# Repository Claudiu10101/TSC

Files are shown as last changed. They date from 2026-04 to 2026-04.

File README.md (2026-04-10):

## 1. Descrierea Detaliată a Funcționalității Hardware

Sistemul este un ceas inteligent (smartwatch) cu consum ultra-redus de energie, bazat pe SoC-ul **nRF52840**, care integrează conectivitate Bluetooth Low Energy (BLE) și un afișaj de tip E-Paper (E-Ink).

### Module și Componente Cheie:
* **Unitatea Centrală (MCU):** **nRF52840** (Cortex-M4F la 64MHz). Este ales pentru suportul hardware de Floating Point (necesar procesării datelor de la senzori) și pentru managementul avansat al energiei.
* **Afișajul (E-Paper):** Spre deosebire de ecranele LCD/OLED, acesta consumă energie **doar la schimbarea imaginii**. Circuitul de control (E-Paper Drive) utilizează un convertor boost format din inductorul **L5 (68µH)** și diodele **MBR0530** pentru a genera tensiunile de ±15V necesare orientării particulelor de pigment din ecran.
* **Managementul Bateriei (Power Management):**
    * **Charger (BQ25180):** Permite încărcarea controlată prin USB și monitorizarea prin I2C.
    * **Fuel Gauge (MAX17048):** Folosește algoritmul *ModelGauge* pentru a estima procentul bateriei fără a necesita un rezistor de descărcare (shunt), economisind energie.
    * **Regulator Buck-Boost (RT6160):** Menține constantă tensiunea de 3.3V chiar și când bateria scade sub acest prag (până la 2.5V), maximizând timpul de utilizare.
* **Senzori și Feedback:**
    * **Accelerometru (BMA423):** Include funcții hardware pentru numărarea pașilor (pedometer) și detectarea gestului de "ridicare mână" (tilt-to-wake), trimițând o întrerupere către MCU pentru a-l trezi din sleep.
    * **Haptic Driver (DRV2605):** Permite generarea de efecte de vibrație complexe (peste 100 de librării incluse) pentru notificări discrete.

### Specificații de Comunicație:
* **I2C (Inter-Integrated Circuit):** Lucrează la 400kHz (Fast Mode). Conectează Charger-ul, Fuel Gauge-ul, IMU-ul și Haptic Driver-ul. Această magistrală este ideală pentru senzori datorită simplității și consumului redus.
* **SPI (Serial Peripheral Interface):** Folosit exclusiv pentru ecranul E-Paper pentru a asigura o rată de transfer a datelor suficient de mare pentru refresh-ul imaginii.

---

## 2. Diagrama bloc

```mermaid
graph TD
    %% -- Nodul Central (Microcontroller) --
    subgraph MCU_Block ["Nucleu Central"]
        nRF52840["nRF52840 SoC (Bluetooth 5 / RF)"]
    end

    %% -- Modulul Power Management --
    subgraph Power_Block ["Management Alimentare"]
        LiPo_Batt(("Baterie LiPo 3.7V"))
        USBC_Conn["Conector USB-C (Alimentare/Date)"]
        Charger_BQ["BQ25180 Charger IC"]
        Fuel_MAX["MAX17048 Fuel Gauge"]
        Reg_RT["RT6160 Buck-Boost Regulator"]
    end

    %% -- Modulul Afișaj --
    subgraph Display_Block ["Interfață Vizuală"]
        FPC_Conn["Conector FPC 24p"]
        EPD_Driver["Circuit Comandă E-Paper"]
        EPD_Screen["Ecran E-Paper (E-Ink)"]
    end

    %% -- Modulul Senzori & Feedback --
    subgraph Sensor_Feedback_Block ["Senzori și Actuatori"]
        IMU_BMA["BMA423 Accelerometru"]
        Haptic_DRV["DRV2605 Haptic Driver"]
        Haptic_Mot(("Motor Vibrații"))
    end

    %% -- Linii de Alimentare --
    USBC_Conn ==> Charger_BQ
    LiPo_Batt <==> Charger_BQ
    LiPo_Batt -.-> Fuel_MAX
    Charger_BQ ==> Reg_RT
    Reg_RT ==> nRF52840
    Reg_RT ==> IMU_BMA
    Reg_RT ==> FPC_Conn
    Reg_RT ==> Haptic_DRV

    %% -- Linii de Date --
    nRF52840 <-->|I2C| Charger_BQ
    nRF52840 <-->|I2C| Fuel_MAX
    nRF52840 <-->|I2C| IMU_BMA
    nRF52840 <-->|I2C| Haptic_DRV
    nRF52840 -->|SPI| FPC_Conn
    FPC_Conn <--> EPD_Driver
    EPD_Driver ==> EPD_Screen
```

## 3. Configurarea Pinilor nRF52840 (Pinout Mapping)

Alegerea pinilor pe nRF52840 este critică pentru a evita interferențele și pentru a optimiza rutarea semnalelor RF.

| Pin MCU | Funcție Schematic | Explicație și Justificare |
| :--- | :--- | :--- |
| **P0.26 / P0.27** | **SDA / SCL** | **Magistrala I2C.** Sunt pini digitali generali. S-au ales acești pini pentru a păstra magistrala de senzori grupată fizic pe PCB. |
| **P1.01** | **EPD_BUSY** | **Intrare digitală.** MCU citește acest pin pentru a ști când ecranul a terminat operațiunea de refresh (activ high). |
| **P1.02** | **EPD_RES** | **Reset ecran.** Pin digital folosit pentru inițializarea hardware a controlerului de display. |
| **P1.03** | **EPD_DC** | **Data/Command.** Semnal de control SPI care indică dacă datele trimise sunt comenzi sau pixeli. |
| **P1.04** | **EPD_CS** | **Chip Select.** Activează comunicația SPI cu ecranul. |
| **P1.05** | **EPD_SCK** | **SPI Clock.** Generat de MCU pentru sincronizarea datelor către ecran. |
| **P1.06** | **EPD_MOSI** | **Master Out Slave In.** Linia principală de date către afișaj. |
| **P0.11** | **INT_IMU** | **Intrare Întrerupere.** Conectat la pinul INT1 al BMA423. Trezește procesorul din modul System OFF la detectarea mișcării. |
| **P0.03** | **HAPTIC_EN** | **Trigger.** Activează driverul de vibrații. Poate fi folosit și cu PWM pentru intensitate variabilă. |
| **P0.02, P0.29, P0.31** | **Buttons (UP, ENT, DN)** | **Interfață Utilizator.** Configurați cu Pull-Up intern. Sunt pini capabili de "Sense" pentru a trezi dispozitivul din moduri de consum ultra-redus. |

### Calcule și Considerente de Consum:
1.  **Mod Sleep (Deep Sleep):** Cu nRF52840 în modul *System ON Idle* și senzorii în mod *Low Power*, consumul estimat este de aproximativ **15-20 µA**.
2.  **Refresh Ecran:** În timpul celor 1-2 secunde de refresh E-Paper, consumul sare la **5-10 mA** datorită convertorului boost.
3.  **Baterie:** Folosind o baterie LiPo de 100mAh, cu un management corect al sleep-ului, autonomia poate depăși **2-3 săptămâni**.

Acest design respectă rigurozitatea cerută în cadrul cursului TSC, punând accent pe utilizarea eficientă a perifericelor hardware ale nRF52840 și pe independența modulelor față de CPU prin utilizarea întreruperilor.

### 4. Bill of materials

| Cantitate | Componentă / Modul | Designator (Parts) | Descriere Scurtă | Link Achiziție / Resurse | Datasheet / Link Producător |
| :--- | :--- | :--- | :--- | :--- | :--- |
| 1 | **nRF52840** | U$1 | [cite_start]Microcontroler Bluetooth [cite: 738, 740] | [Mouser/Search](https://www.mouser.com) | [Nordic Semi](https://www.google.com/search?q=https://www.nordicsemi.com) |
| 1 | **2450AT18B100E** | ANT1 | [cite_start]Antenă Chip 2.45GHz [cite: 358, 360] | [cite_start][Arrow Link](https://www.arrow.com/en/products/2450at18b100e/johanson-dielectrics) [cite: 360] | [cite_start][Johanson Tech](https://www.google.com/search?q=https://www.mouser.co.uk/ProductDetail/Johanson-Technology/2450at18b100e) [cite: 364] |
| 1 | **BQ25180YBGR** | IC1 | [cite_start]Charger IC Li-Ion/Polymer [cite: 574, 576] | [cite_start][Mouser Link](https://www.google.com/search?q=https://www.mouser.co.uk/ProductDetail/Texas-Instruments/BQ25180YBGR) [cite: 581] | [cite_start][Texas Instruments](https://www.google.com/search?q=https://www.arrow.com/en/products/bq25180ybgr/texas-instruments) [cite: 576] |
| 1 | **RT6160AWSC** | IC2 | [cite_start]Buck-Boost Regulator [cite: 755, 757] | [cite_start][Mouser Link](https://www.google.com/search?q=https://www.mouser.co.uk/ProductDetail/Richtek/RT6160AWSC) [cite: 762] | [cite_start][Richtek](https://www.google.com/search?q=https://www.mouser.co.uk/ProductDetail/Richtek/RT6160AWSC) [cite: 762] |
| 1 | **BMA423** | IC3 | [cite_start]Accelerometru 3 axe [cite: 559, 561] | [cite_start][Mouser Link](https://www.google.com/search?q=https://www.mouser.co.uk/ProductDetail/Bosch-Sensortec/BMA423) [cite: 566] | [cite_start][Bosch Sensortec](https://www.arrow.com/en/products/bma423/bosch) [cite: 562] |
| 1 | **DRV2605YZFR** | IC4 | [cite_start]Haptic Driver (ERM/LRA) [cite: 604, 606] | [cite_start][Arrow Link](https://www.arrow.com/en/products/drv2605yzfr/texas-instruments) [cite: 606] | [cite_start][Texas Instruments](https://www.arrow.com/en/products/drv2605yzfr/texas-instruments) [cite: 606] |
| 1 | **FTC252012SR47MBCA** | L1 | [cite_start]Inductor 0.47µH [cite: 706, 707] | [cite_start][**JLC Parts (C5832368)**](https://jlcpcb.com/partdetail/6763488-FTC252012SR47MBCA/C5832368) [cite: 712] | [cite_start][TDK](https://jlcpcb.com/partdetail/6763488-FTC252012SR47MBCA/C5832368) [cite: 712] |
| 1 | **KH-TYPE-C-16P** | J2 | [cite_start]Conector USB-C 16 pini [cite: 691, 692] | [cite_start][SnapEDA Link](https://www.snapeda.com/parts/KH-TYPE-C-16P/Kinghelm/view-part/?ref=snap) [cite: 703] | [cite_start][Kinghelm](https://www.snapeda.com/parts/KH-TYPE-C-16P/Kinghelm/view-part/?ref=eda) [cite: 694] |
| 1 | **503480-2400** | J1 | [cite_start]Conector FPC 24 pini [cite: 493, 494] | [cite_start][Mouser Link](https://www.google.com/search?q=https://www.mouser.co.uk/ProductDetail/Molex/503480-2400) [cite: 500] | [cite_start][Molex](https://www.google.com/search?q=https://www.mouser.co.uk/ProductDetail/Molex/503480-2400) [cite: 500] |
| 3 | **MBR0530** | D1, D2, D3 | [cite_start]Diodă Schottky 0.5A 30V [cite: 632, 634] | [cite_start][SnapEDA Link](https://www.snapeda.com/parts/MBR0530/Onsemi/view-part/?ref=snap) [cite: 642] | [cite_start][ON Semi](https://www.snapeda.com/parts/MBR0530/Onsemi/view-part/?ref=eda) [cite: 636] |
| 1 | **USBLC6-2SC6Y** | D4 | [cite_start]Protecție ESD SOT-23-6 [cite: 619, 621] | [cite_start][SnapEDA Link](https://www.snapeda.com/parts/USBLC6-2SC6Y/STMicroelectronics/view-part/?ref=snap) [cite: 629] | [cite_start][STMicro](https://www.snapeda.com/parts/USBLC6-2SC6Y/STMicroelectronics/view-part/?ref=eda) [cite: 622] |
| 1 | **SI1308EDL-T1-GE3** | Q1 | [cite_start]MOSFET N-Ch 30V 1.5A [cite: 646, 647] | [cite_start][SnapEDA Link](https://www.snapeda.com/parts/SI1308EDL-T1-GE3/Vishay+Siliconix/view-part/?ref=snap) [cite: 656] | [cite_start][Vishay](https://www.snapeda.com/parts/SI1308EDL-T1-GE3/Vishay+Siliconix/view-part/?ref=eda) [cite: 648] |
| 3 | **EVP-AKE31A** | SW1-SW3 | [cite_start]Întrerupător (Switch) [cite: 326, 327] | [Panasonic Search](https://www.mouser.com) | [Panasonic](https://www.mouser.com) |
| 1 | **TC2030-IDC** | J3 | [cite_start]Adaptor programare 6 pini [cite: 770, 771] | [Tag-Connect](https://www.tag-connect.com) | [cite_start][Tag-Connect](https://www.tag-connect.com) [cite: 776] |

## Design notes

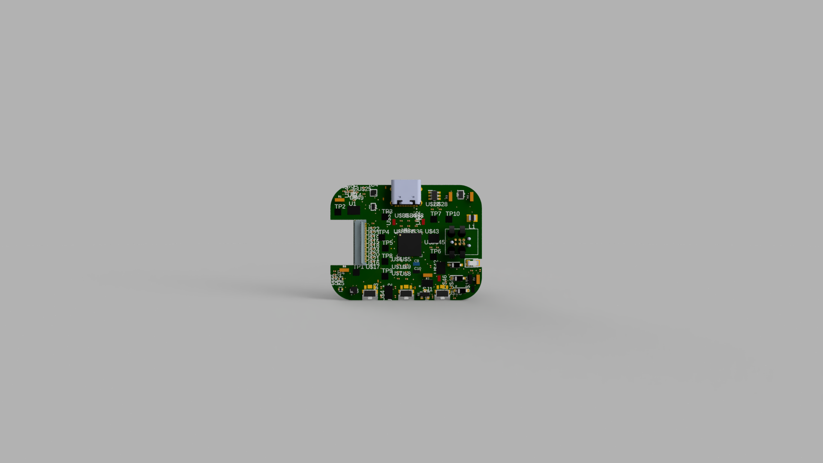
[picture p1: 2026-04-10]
Images/170cff6c-68ed-45f0-8952-ea8ea06512d7.PNG

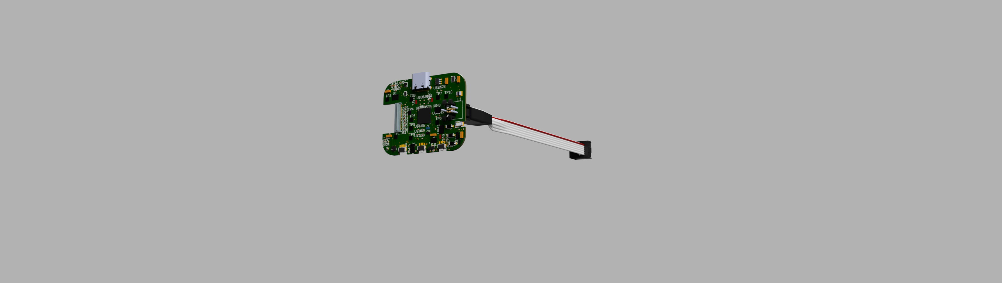
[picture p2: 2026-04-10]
Images/InkTime.fbrd_2026-Apr-10_02-35-59PM-000_CustomizedView54129638116.png

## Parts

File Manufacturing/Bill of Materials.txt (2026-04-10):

Partlist exported from Fusion Hub: Alexe   Project: iiytkhgjh  Board: InkTime.fbrd at 4/10/2026 7:06 AM

Qty Value                                            Device                                                                       Package                                                                                                                Parts                                                Description                                                                                                               ARROW_PART_NUMBER ARROW_PRICE-STOCK                                                                                AVAILABILITY CATEGORY  CHECK_PRICES                                                                       DATASHEET DESCRIPTION                                                                                              HEIGHT                                    JLCPCB       MANUFACTURER                                        MANUFACTURER_NAME                                                MANUFACTURER_PART_NUMBER MF                 MOUSER_PART_NUMBER MOUSER_PRICE-STOCK                                                                                           MP                                                                                                       MPN OPERATING_TEMPERATURE PACKAGE                     PACKAGE_SIZE PACKAGE_TYPE  PART_STATUS                  POPULARITY PRICE PROD_ID    PURCHASE-URL                                                                                                                           ROHS SERIES SNAPEDA_LINK                                                                                                                                    SUBCATEGORY TEMPERATURE_COEFFICIENT THERMALLOSS                                                                         TOLERANCE TP_SIGNAL_NAME TYPE VALUE             
1                                                    ESP32_C6_LIBRARY_7_JUMPER_SJ                                                 ESP32_C6_LIBRARY_7_JUMPER_SJ                                                                                           SJ1                                                  SMD solder JUMPER                                                                                                                                                                                                                                                                                                                                                                                                                                                                                                                                                                                                                                                                                                                                                                                                                                                                                                                                                                                                                                        3                                                                                                                                                                                                                                                                                                                                                                                                                                                                                                      
8                                                    NORDIC_NRF_3_CAPACITOR_0201_L                                                NORDIC_NRF_3_RESC0201_L                                                                                                U$47, U$48, U$49, U$50, U$51, U$52, U$53, U$54       Generic chip capacitor                                                                                                                                                                                                                                                                                                                                                                                                                                                                                                                                                                                                                                                                                                                                                                                                                                                                                                                                                                                                                                                                                                                                                                                                                                                                                                                                                                                                                                                                                                                                          
4   0                                                0OHM-0603-1/10W                                                              0603                                                                                                                   R1, R2, R3, R6                                       0O resistor                                                                                                                                                                                                                                                                                                                                                                                                                                                                                                                                                                                                                                                                                                                                                                                                                                                                                                                                                                                                                                                               RES-08609                                                                                                                                                                                                                                                                                                                                                                                                                                                           0                 
3   0.1uF                                            NORDIC_NRF_3_CAPACITOR_0201_L                                                NORDIC_NRF_3_RESC0201_L                                                                                                U$14, U$25, U$27                                     Generic chip capacitor                                                                                                                                                                                                                                                                                                                                                                                                                                                                                                                                                                                                                                                                                                                                                                                                                                                                                                                                                                                                                                                                                                                                                                                                                                                                                                                                                                                                                                                                                                                                          
1   0.1uF/50V                                        NORDIC_NRF_3_CAPACITOR_0201_L                                                NORDIC_NRF_3_RESC0201_L                                                                                                U$24                                                 Generic chip capacitor                                                                                                                                                                                                                                                                                                                                                                                                                                                                                                                                                                                                                                                                                                                                                                                                                                                                                                                                                                                                                                                                                                                                                                                                                                                                                                                                                                                                                                                                                                                                          
1   0.47                                             0OHM-0603-1/10W                                                              0603                                                                                                                   R7                                                   0O resistor                                                                                                                                                                                                                                                                                                                                                                                                                                                                                                                                                                                                                                                                                                                                                                                                                                                                                                                                                                                                                                                               RES-08609                                                                                                                                                                                                                                                                                                                                                                                                                                                           0                 
3   100nF                                            NORDIC_NRF_3_CAPACITOR_0201_L                                                NORDIC_NRF_3_RESC0201_L                                                                                                U$5, U$10, U$37                                      Generic chip capacitor                                                                                                                                                                                                                                                                                                                                                                                                                                                                                                                                                                                                                                                                                                                                                                                                                                                                                                                                                                                                                                                                                                                                                                                                                                                                                                                                                                                                                                                                                                                                          
1   100nF                                            PERFECT_0402_CAP_0402                                                        PERFECT_0402_0402                                                                                                      C10                                                  0402 (1005 Metric)                                                                                                                                                                                                                                                                                                                                                                                                                                                                                                                                                                                                                                                                                                                                                                                                                                                                                                                                                                                                                                                                                                                                                                                                                                                                                                                                                                                                                                                                                                                                              
1   100pF                                            NORDIC_NRF_3_CAPACITOR_0201_L                                                NORDIC_NRF_3_RESC0201_L                                                                                                U$38                                                 Generic chip capacitor                                                                                                                                                                                                                                                                                                                                                                                                                                                                                                                                                                                                                                                                                                                                                                                                                                                                                                                                                                                                                                                                                                                                                                                                                                                                                                                                                                                                                                                                                                                                          
1   10k                                              0OHM-0603-1/10W                                                              0603                                                                                                                   R16                                                  0O resistor                                                                                                                                                                                                                                                                                                                                                                                                                                                                                                                                                                                                                                                                                                                                                                                                                                                                                                                                                                                                                                                               RES-08609                                                                                                                                                                                                                                                                                                                                                                                                                                                           0                 
1   10uF                                             NORDIC_NRF_3_CAPACITOR_0201_L                                                NORDIC_NRF_3_RESC0201_L                                                                                                U$13                                                 Generic chip capacitor                                                                                                                                                                                                                                                                                                                                                                                                                                                                                                                                                                                                                                                                                                                                                                                                                                                                                                                                                                                                                                                                                                                                                                                                                                                                                                                                                                                                                                                                                                                                          
1   10uH                                             NORDIC_NRF_2_INDUCTOR_0402_L                                                 NORDIC_NRF_2_RESC0402_L                                                                                                U$32                                                 Generic chip inductor                                                                                                                                                                                                                                                                                                                                                                                                                                                                                                                                                                                                                                                                                                                                                                                                                                                                                                                                                                                                                                                                                                                                                                                                                                                                                                                                                                                                                                                                                                                                           
4   12pF                                             NORDIC_NRF_3_CAPACITOR_0201_L                                                NORDIC_NRF_3_RESC0201_L                                                                                                U$2, U$3, U$44, U$45                                 Generic chip capacitor                                                                                                                                                                                                                                                                                                                                                                                                                                                                                                                                                                                                                                                                                                                                                                                                                                                                                                                                                                                                                                                                                                                                                                                                                                                                                                                                                                                                                                                                                                                                          
1   15nH                                             NORDIC_NRF_2_INDUCTOR_0402_L                                                 NORDIC_NRF_2_RESC0402_L                                                                                                U$33                                                 Generic chip inductor                                                                                                                                                                                                                                                                                                                                                                                                                                                                                                                                                                                                                                                                                                                                                                                                                                                                                                                                                                                                                                                                                                                                                                                                                                                                                                                                                                                                                                                                                                                                           
2   1pF                                              NORDIC_NRF_3_CAPACITOR_0201_L                                                NORDIC_NRF_3_RESC0201_L                                                                                                U$41, U$42                                           Generic chip capacitor
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

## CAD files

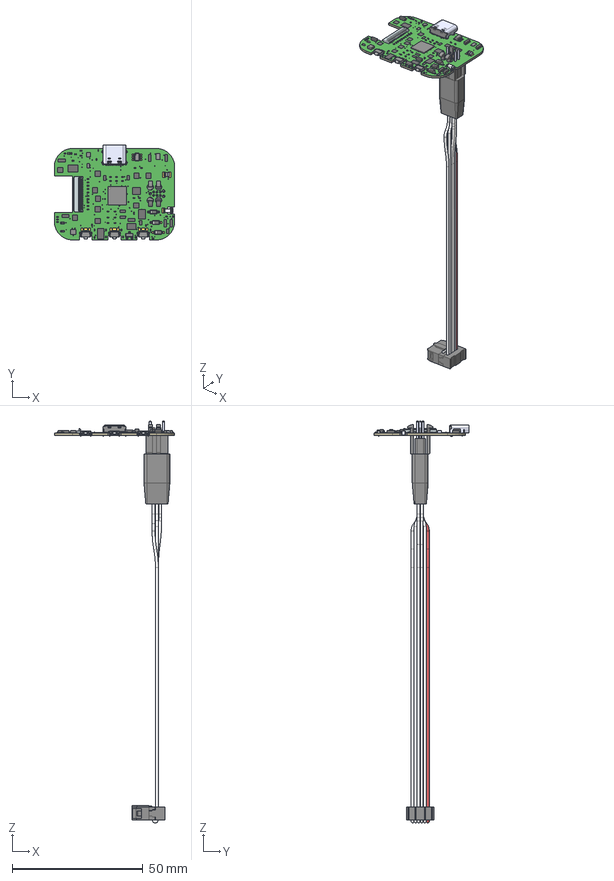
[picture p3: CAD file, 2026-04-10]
Mechanical/InkTime.step
46.0 x 36.3 x 153.6 mm

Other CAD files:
Mechanical/InkTime.f3d

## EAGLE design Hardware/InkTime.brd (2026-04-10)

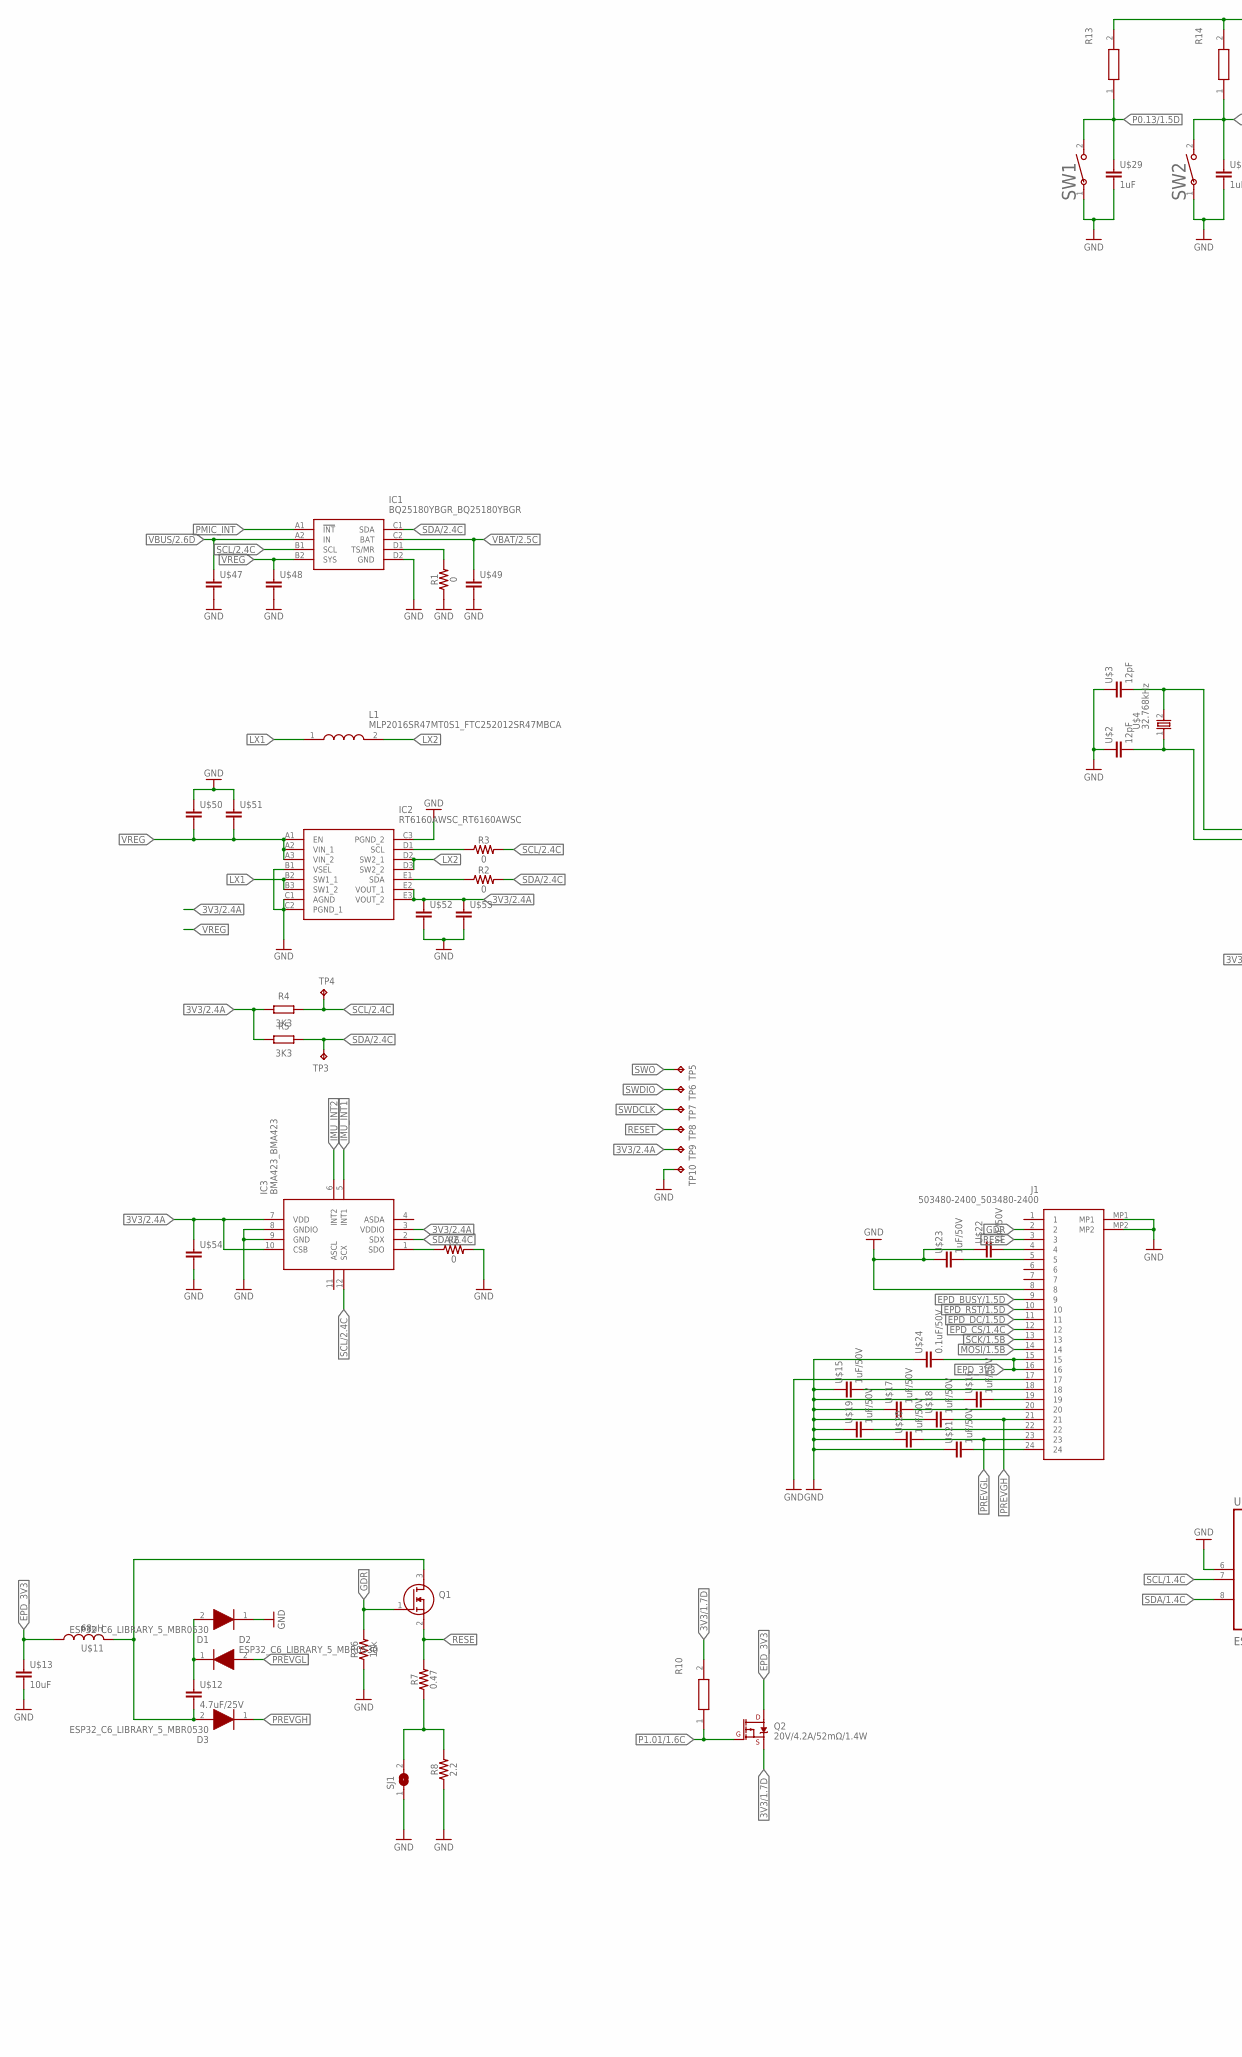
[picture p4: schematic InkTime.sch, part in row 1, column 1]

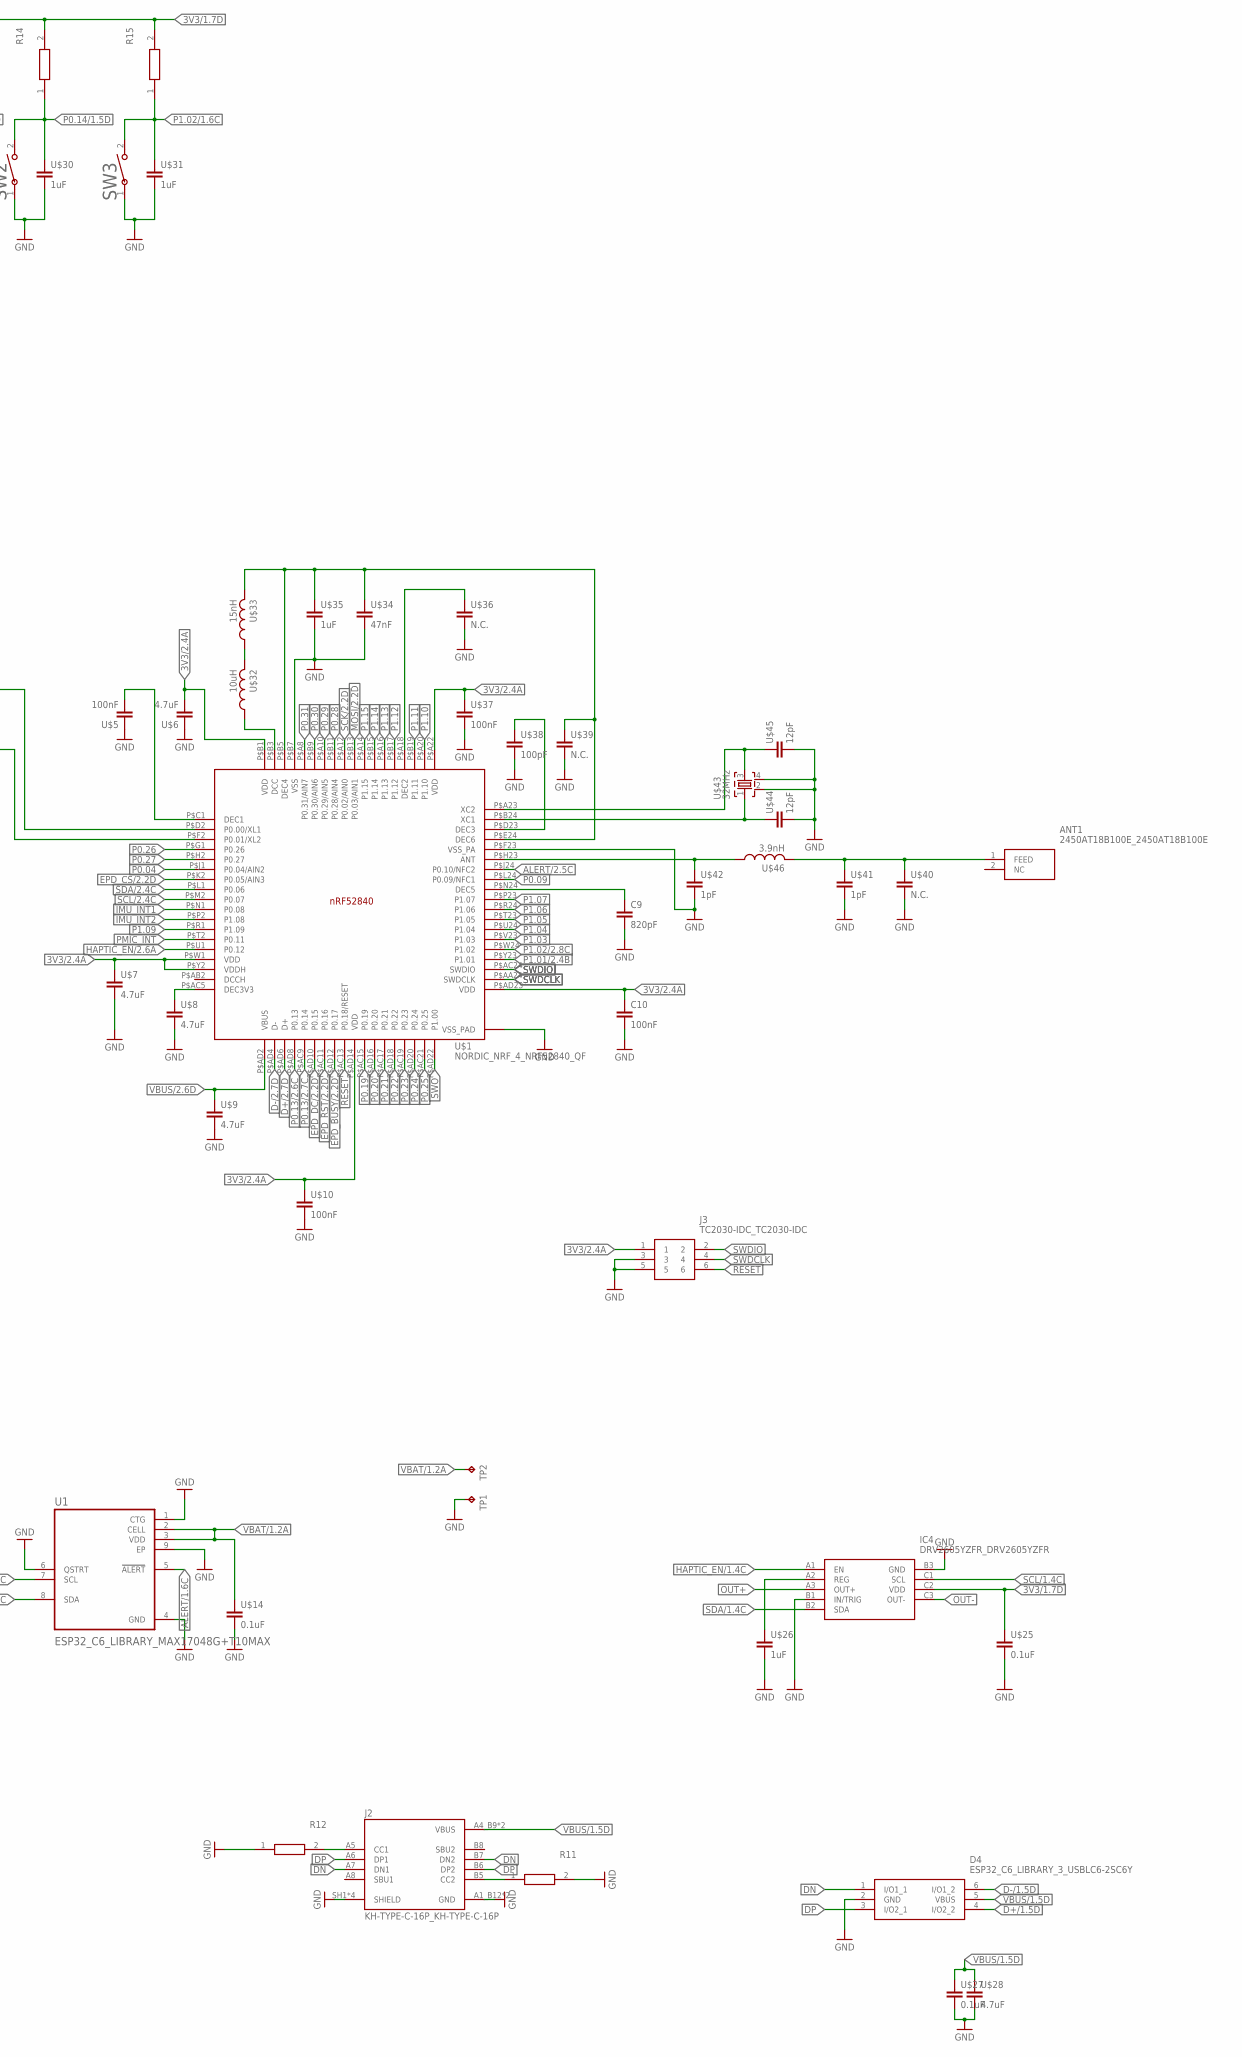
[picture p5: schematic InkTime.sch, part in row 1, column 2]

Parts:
ANT1: 2450AT18B100E_2450AT18B100E; 2450AT18B100E_ANTC3216X140N
C9: 820pF; PERFECT_0402_0402
C10: 100nF; PERFECT_0402_0402
D1, D2, D3: ESP32_C6_LIBRARY_5_MBR0530; ESP32_C6_LIBRARY_5_SOD3716X135N
D4: ESP32_C6_LIBRARY_3_USBLC6-2SC6Y; ESP32_C6_LIBRARY_3_SOT95P280X145-6N
IC1: BQ25180YBGR_BQ25180YBGR; BQ25180YBGR_BGA8C40P2X4_100X155X50
IC2: RT6160AWSC_RT6160AWSC; RT6160AWSC_BGA15C40P3X5_140X230X60
IC3: BMA423_BMA423
IC4: DRV2605YZFR_DRV2605YZFR; DRV2605YZFR_BGA9C50P3X3_144X144X62
J1: 503480-2400_503480-2400; 503480-2400_5034802400
J2: KH-TYPE-C-16P_KH-TYPE-C-16P; KH-TYPE-C-16P_KINGHELM_KH-TYPE-C-16P
J3: TC2030-IDC_TC2030-IDC; TC2030-IDC_TC2030IDC
L1: MLP2016SR47MT0S1_FTC252012SR47MBCA; MLP2016SR47MT0S1_INDC2016X100N
Q1: ESP32_C6_LIBRARY_6_SI1308EDL-T1-GE3; ESP32_C6_LIBRARY_6_SOT65P210X110-3N
Q2: 20V/4.2A/52mΩ/1.4W; ESP32_C6_LIBRARY_4_ESP32_C6_LIBRARY_4_ESP32_C6_LIBRARY_4_ES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
R1, R2, R3, R6: 0; 0603
R4, R5: 3K3; RESC1005X40
R7: 0.47; 0603
R8: 2.2; 0603
R10, R11, R13, R14, R15: CPF0201D7K68C1_CPF0201D7K68C1; CPF0201D7K68C1_0201
R12: 5k1; CPF0201D7K68C1_0201
R16: 10k; 0603
SJ1: ESP32_C6_LIBRARY_7_JUMPER_SJ
SW1, SW2, SW3: 2025-10-22_07-23-44_LIBRARY_EVP-AKE31AEVP-AKE31A; 2025-10-22_07-23-44_LIBRARY_SW_EVP-AKE31A_PAN
TP1, TP2, TP3, TP4, TP5, TP6, TP7, TP8, TP9, TP10: HECTOR_WATCH_1_TPTP20R; HECTOR_WATCH_1_TP20R
U1: ESP32_C6_LIBRARY_MAX17048G+T10MAX; ESP32_C6_LIBRARY_SON50P200X200X80-9N
U$1: NORDIC_NRF_4_NRF52840_QF; NORDIC_NRF_4_AQFN50P700X700X85_HS-74N
U$2, U$3, U$44, U$45: 12pF; NORDIC_NRF_3_RESC0201_L
U$4: 32.768kHz; NORDIC_NRF_1_XTAL_3215_N
U$5, U$10, U$37: 100nF; NORDIC_NRF_3_RESC0201_L
U$6, U$7, U$8, U$9, U$28: 4.7uF; NORDIC_NRF_3_RESC0201_L
U$11: 68uH; NORDIC_NRF_2_RESC0402_L
U$12: 4.7uF/25V; NORDIC_NRF_3_RESC0201_L
U$13: 10uF; NORDIC_NRF_3_RESC0201_L
U$14, U$25, U$27: 0.1uF; NORDIC_NRF_3_RESC0201_L
U$15, U$16, U$17, U$18, U$19, U$20, U$21, U$22, U$23: 1uF/50V; NORDIC_NRF_3_RESC0201_L
U$24: 0.1uF/50V; NORDIC_NRF_3_RESC0201_L
U$26, U$29, U$30, U$31, U$35: 1uF; NORDIC_NRF_3_RESC0201_L
U$32: 10uH; NORDIC_NRF_2_RESC0402_L
U$33: 15nH; NORDIC_NRF_2_RESC0402_L
U$34: 47nF; NORDIC_NRF_3_RESC0201_L
U$36, U$39, U$40: N.C.; NORDIC_NRF_3_RESC0201_L
U$38: 100pF; NORDIC_NRF_3_RESC0201_L
U$41, U$42: 1pF; NORDIC_NRF_3_RESC0201_L
U$43: 32MHz; NORDIC_NRF_BT-XTAL_2016_N
U$46: 3.9nH; NORDIC_NRF_2_RESC0402_L
U$47, U$48, U$49, U$50, U$51, U$52, U$53, U$54: NORDIC_NRF_3_CAPACITOR_0201_L; NORDIC_NRF_3_RESC0201_L

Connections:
3V3/1.7D: IC4.C2 (VDD), Q2.2 (S), R10.2, R13.2, R14.2, R15.2, U$25.1
3V3/2.4A: C10.1, IC2.E2 (VOUT_1), IC2.E3 (VOUT_2), IC3.3 (VDDIO), IC3.7 (VDD), IC3.10 (CSB), J3.1, R4.1, R5.1, TP9.TP, U$1.P$A22 (VDD), U$1.P$AD14 (VDD), U$1.P$AD23 (VDD), U$1.P$B1 (VDD), U$1.P$W1 (VDD), U$1.P$Y2 (VDDH), U$6.2, U$7.1, U$10.1, U$37.1, U$52.1, U$53.1, U$54.1
ALERT/1.6C: U1.5 (!ALERT)
ALERT/2.5C: U$1.P$J24 (P0.10/NFC2)
D+/1.5D: D4.4 (I/O2_2)
D+/2.7D: U$1.P$AD6 (D+)
D-/1.5D: D4.6 (I/O1_2)
D-/2.7D: U$1.P$AD4 (D-)
DN: D4.1 (I/O1_1), J2.A7 (DN1), J2.B7 (DN2)
DP: D4.3 (I/O2_1), J2.A6 (DP1), J2.B6 (DP2)
EPD_3V3: J1.15, J1.16, Q2.3 (D), U$11.1, U$13.1, U$24.2
EPD_BUSY/1.5D: J1.9
EPD_BUSY/2.2D: U$1.P$AD12 (P0.17)
EPD_CS/1.4C: J1.12
EPD_CS/2.2D: U$1.P$K2 (P0.05/AIN3)
EPD_DC/1.5D: J1.11
EPD_DC/2.2D: U$1.P$AD10 (P0.15)
EPD_RST/1.5D: J1.10
EPD_RST/2.2D: U$1.P$AC11 (P0.16)
GDR: J1.2, Q1.1 (G), R16.2
GND: C9.2, C10.2, D1.1 (K), D4.2 (GND), IC1.D2 (GND), IC2.B1 (VSEL), IC2.C1 (AGND), IC2.C2 (PGND_1), IC2.C3 (PGND_2), IC3.8 (GNDIO), IC3.9 (GND), IC4.B1 (IN/TRIG), IC4.B3 (GND), J1.8, J1.17, J1.MP1, J1.MP2, J2.A1_B12 (GND), J2.A12_B1 (GND), J2.SH1 (SHIELD), J2.SH2 (SHIELD), J2.SH3 (SHIELD), J2.SH4 (SHIELD), J3.3, J3.5, R1.1, R6.2, R8.1, R11.2, R12.1, R16.1, SJ1.1, SW1.1, SW2.1, SW3.1, TP1.TP, TP10.TP, U1.1 (CTG), U1.4 (GND), U1.6 (QSTRT), U1.9 (EP), U$1.P$74 (VSS_PAD), U$1.P$75 (VSS_PAD), U$1.P$76 (VSS_PAD), U$1.P$77 (VSS_PAD), U$1.P$78 (VSS_PAD), U$1.P$79 (VSS_PAD), U$1.P$80 (VSS_PAD), U$1.P$81 (VSS_PAD), U$1.P$82 (VSS_PAD), U$1.P$83 (VSS_PAD), U$1.P$84 (VSS_PAD), U$1.P$85 (VSS_PAD), U$1.P$86 (VSS_PAD), U$1.P$87 (VSS_PAD), U$1.P$88 (VSS_PAD), U$1.P$89 (VSS_PAD), U$1.P$90 (VSS_PAD), U$1.P$B7 (VSS), U$1.P$F23 (VSS_PA), U$2.1, U$3.1, U$5.1, U$6.1, U$7.2, U$8.2, U$9.2, U$10.2, U$13.2, U$14.2, U$15.1, U$16.1, U$17.1, U$18.1, U$19.1, U$20.1, U$21.1, U$22.1, U$23.1, U$24.1, U$25.2, U$26.2, U$27.2, U$28.2, U$29.2, U$30.2, U$31.2, U$34.2, U$35.2, U$36.2, U$37.2, U$38.2, U$39.2, U$40.2, U$41.2, U$42.2, U$43.2, U$43.4, U$44.2, U$45.2, U$47.2, U$48.2, U$49.2, U$50.1, U$51.1, U$52.2, U$53.2, U$54.2
HAPTIC_EN/1.4C: IC4.A1 (EN)
HAPTIC_EN/2.6A: U$1.P$U1 (P0.12)
IMU_INT1: IC3.5 (INT1), U$1.P$N1 (P0.08)
IMU_INT2: IC3.6 (INT2), U$1.P$P2 (P1.08)
LX1: IC2.B2 (SW1_1), IC2.B3 (SW1_2), L1.1
LX2: IC2.D2 (SW2_1), IC2.D3 (SW2_2), L1.2
MOSI/1.5B: J1.14
MOSI/2.2D: U$1.P$B13 (P0.03/AIN1)
unnamed: U$1.P$AC5 (DEC3V3), U$8.1
unnamed: J2.A5 (CC1), R12.2
unnamed: D3.2 (A), Q1.3 (D), U$11.2, U$12.2
unnamed: IC2.D1 (SCL), R3.1
unnamed: IC3.1 (SDO), R6.1
unnamed: IC1.D1 (TS/MR), R1.2
unnamed: IC2.E1 (SDA), R2.1
unnamed: U$1.P$D2 (P0.00/XL1), U$3.2, U$4.2
unnamed: U$1.P$B5 (DEC4), U$1.P$E24 (DEC6), U$33.2, U$34.1, U$35.1, U$39.1
unnamed: U$1.P$B3 (DCC), U$32.1
unnamed: D1.2 (A), D2.1 (K), U$12.1
unnamed: U$32.2, U$33.1
unnamed: J2.B5 (CC2), R11.1
unnamed: R7.1, R8.2, SJ1.2
unnamed: U$1.P$A18 (DEC2), U$36.1
unnamed: U$1.P$A23 (XC2), U$43.3, U$45.1
unnamed: U$1.P$D23 (DEC3), U$38.1
unnamed: IC4.A2 (REG), U$26.1
unnamed: U$1.P$C1 (DEC1), U$5.2
unnamed: U$1.P$F2 (P0.01/XL2), U$2.2, U$4.1
unnamed: U$1.P$H23 (ANT), U$42.1, U$46.1
unnamed: J1.18, U$15.2
unnamed: J1.19, U$16.2
unnamed: J1.20, U$17.2
unnamed: J1.22, U$19.2
unnamed: U$1.P$B24 (XC1), U$43.1, U$44.1
unnamed: J1.24, U$21.2
unnamed: J1.4, U$22.2
unnamed: J1.5, U$23.2
unnamed: ANT1.1 (FEED), U$40.1, U$41.1, U$46.2
unnamed: C9.1, U$1.P$N24 (DEC5)
OUT+: IC4.A3 (OUT+)
OUT-: IC4.C3 (OUT-)
P0.04: U$1.P$J1 (P0.04/AIN2)
P0.09: U$1.P$L24 (P0.09/NFC1)
P0.13/1.5D: R13.1, SW1.2, U$29.1
P0.13/2.6C: U$1.P$AD8 (P0.13)
P0.13/2.7C: U$1.P$AC9 (P0.14)
P0.14/1.5D: R14.1, SW2.2, U$30.1
P0.19: U$1.P$AC15 (P0.19)
P0.20: U$1.P$AD16 (P0.20)
P0.21: U$1.P$AC17 (P0.21)
P0.22: U$1.P$AD18 (P0.22)
P0.23: U$1.P$AC19 (P0.23)
P0.24: U$1.P$AD20 (P0.24)
P0.25: U$1.P$AC21 (P0.25)
P0.26: U$1.P$G1 (P0.26)
P0.27: U$1.P$H2 (P0.27)
P0.28: U$1.P$B11 (P0.28/AIN4)
P0.29: U$1.P$A10 (P0.29/AIN5)
P0.30: U$1.P$B9 (P0.30/AIN6)
P0.31: U$1.P$A8 (P0.31/AIN7)
P1.01/1.6C: Q2.1 (G), R10.1
P1.01/2.4B: U$1.P$Y23 (P1.01)
P1.02/1.6C: R15.1, SW3.2, U$31.1
P1.02/2.8C: U$1.P$W24 (P1.02)
P1.03: U$1.P$V23 (P1.03)
P1.04: U$1.P$U24 (P1.04)
P1.05: U$1.P$T23 (P1.05)
P1.06: U$1.P$R24 (P1.06)
P1.07: U$1.P$P23 (P1.07)
P1.09: U$1.P$R1 (P1.09)
P1.10: U$1.P$A20 (P1.10)
P1.11: U$1.P$B19 (P1.11)
P1.12: U$1.P$B17 (P1.12)
P1.13: U$1.P$A16 (P1.13)
P1.14: U$1.P$B15 (P1.14)
P1.15: U$1.P$A14 (P1.15)
PMIC_INT: IC1.A1 (!INT), U$1.P$T2 (P0.11)
PREVGH: D3.1 (K), J1.21, U$18.2
PREVGL: D2.2 (A), J1.23, U$20.2
RESE: J1.3, Q1.2 (S), R7.2
RESET: J3.6, TP8.TP, U$1.P$AC13 (P0.18/RESET)
SCK/1.5B: J1.13
SCK/2.2D: U$1.P$A12 (P0.02/AIN0)
SCL/1.4C: IC4.C1 (SCL), U1.7 (SCL)
SCL/2.4C: IC1.B1 (SCL), IC3.12 (SCX), R3.2, R4.2, TP4.TP, U$1.P$M2 (P0.07)
SDA/1.4C: IC4.B2 (SDA), U1.8 (SDA)
SDA/2.4C: IC1.C1 (SDA), IC3.2 (SDX), R2.2, R5.2, TP3.TP, U$1.P$L1 (P0.06)
SWDCLK: J3.4, TP7.TP, U$1.P$AA24 (SWDCLK)
SWDIO: J3.2, TP6.TP, U$1.P$AC24 (SWDIO)
SWO: TP5.TP, U$1.P$AD22 (P1.00)
VBAT/1.2A: TP2.TP, U1.2 (CELL), U1.3 (VDD), U$14.1
VBAT/2.5C: IC1.C2 (BAT), U$49.1
VBUS/1.5D: D4.5 (VBUS), J2.A4_B9 (VBUS), J2.A9_B4 (VBUS), U$27.1, U$28.1
VBUS/2.6D: IC1.A2 (IN), U$1.P$AD2 (VBUS), U$9.1, U$47.1
VREG: IC1.B2 (SYS), IC2.A1 (EN), IC2.A2 (VIN_1), IC2.A3 (VIN_2), U$48.1, U$50.2, U$51.2

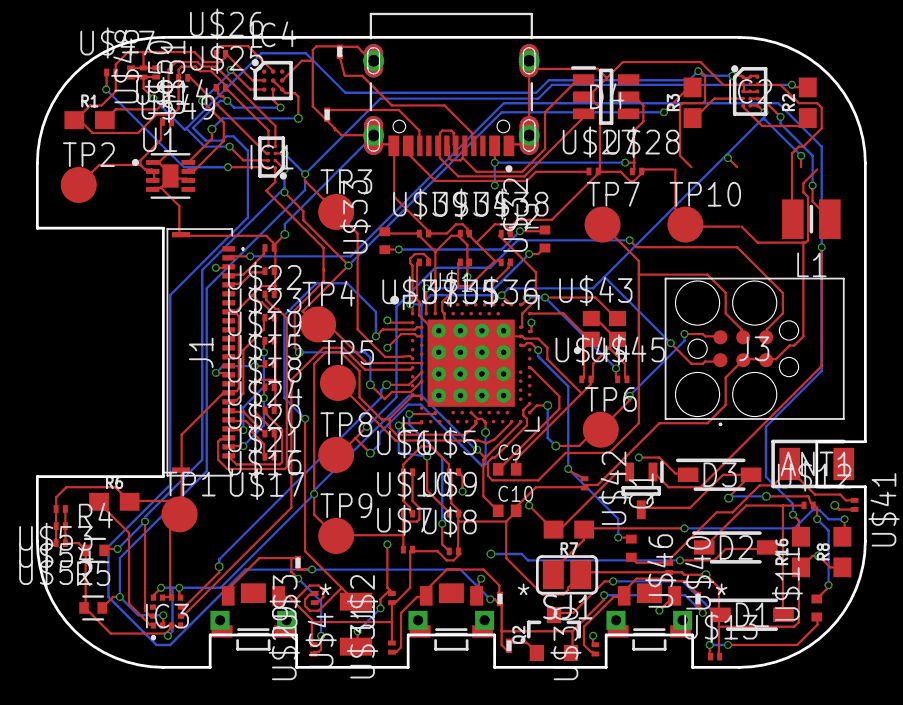
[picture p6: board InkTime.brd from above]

Board: 4 copper layers, 46.0 x 35.0 mm, 101 parts (0 on the bottom side), 63 nets.

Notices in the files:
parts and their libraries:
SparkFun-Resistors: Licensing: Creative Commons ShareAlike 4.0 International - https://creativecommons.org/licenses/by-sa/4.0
